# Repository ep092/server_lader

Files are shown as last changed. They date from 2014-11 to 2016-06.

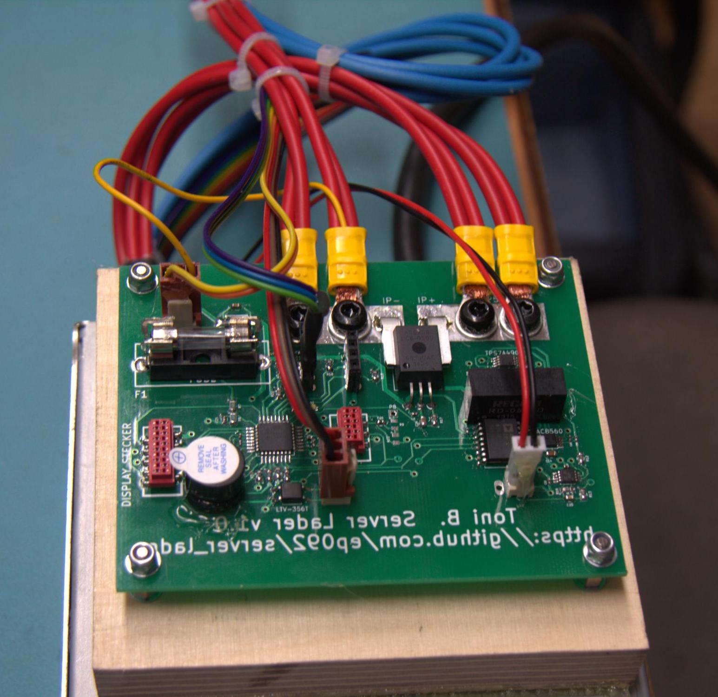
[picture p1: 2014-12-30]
Bilder/Aufbau_phil_2_vorn.JPG

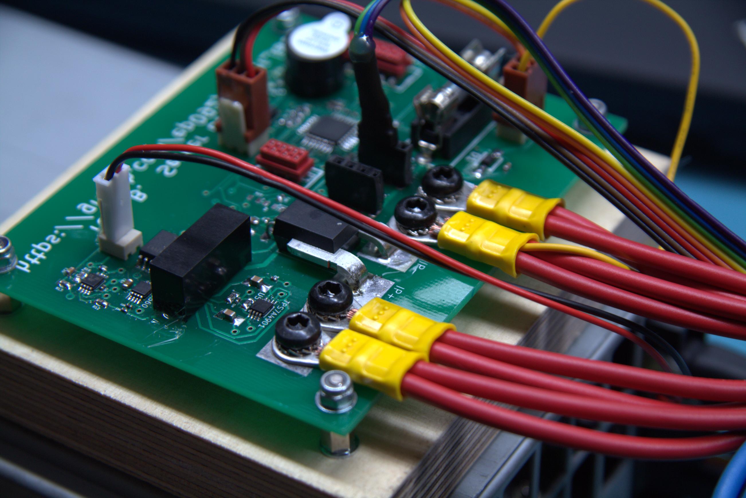
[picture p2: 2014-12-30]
Bilder/Aufbau_phil_3_detail.JPG

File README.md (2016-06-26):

# server_lader

## Umbau eines ESP120 zu einem Ladegerät

### Trivia:
Das ESP120 ist ein 3kW starkes Servernetzteil mit einer Ausgangsspannung von standardmäßig 52V und bis zu >50A. Das Netzteil lässt sich allerdings leicht auf andere Spannungen umrüsten, um z.B. als Akkulader oder sehr potentes Labornetzteil eingesetzt zu werden.

### Was tut dieses Projekt?
dieses Projekt soll die zur Spannungsverstellung nötige Hilfsspannung aus den vom Netzteil zusätzlich bereitgestellten 5V erzeugen, die Ausgangsspannung regeln und für einen Ladestrom nach einem Ladeprogramm, das extern eingespeist wird, einstellen. Das Netzteil muss nur minimal gemoddet werden.

### Der Mod:
siehe elweb, eigene Bilder liegen im Unterordner "Bilder".
Einfach gesagt, werden an den beiden Pads des Potis "RV..." Kabel angelötet, die dann mit der Steuerplatine verbunden werden. Hier wird die Sollwertspannung eingespeist.

Es existieren Messwerte für 3 Sollwertspannungen:

* 61V 35,4 kOhm (-1,5V am Poti)
* 60V 42,5 kOhm (-1,3V am Poti)
* 59V 51,6 kOhm (-1,1V am Poti)

## Umbau auf eine andere Spannung für die Überspannungsabschaltung
Das Netzteil besitzt zusätzlich zur Regelspannung, die am Poti zu verändern ist, eine feste Spannung, bei der eine Überspannungsabschaltung stattfindet. Die soll das Netzteil und die angeschlossenen Verbraucher schützen. Teilweise ist es jedoch nötig, nahe an 60V zu kommen, beispielsweise, wenn man einen 48V-Bleiakkupack laden will. Daher ist in diesen Fällen die Überspannungsabschaltung auf einen leicht höheren Spannungswert zu verschieben. 

Dazu ist es notwendig einen zusätzlichen Widerstand parallel zu den bereits vorhandenen auf einer der Platinen einzulöten. Es handelt sich um einen SMD-Widerstand in Bauform 0805 mit dem Wert "473" also 47 kOhm, der direkt neben einem SMD-Bauteil im Gehäuse SOT-223-3 liegt. Im Ordner "Bilder" ist die Stelle zu sehen, wo der Widerstand eingelötet werden muss.

Wenn man über die bereits verbauten Widerstände im eingebauten Zustand misst, kommt man auf 4,096 Ohm. Mit einem parallel geschaltenen 51,6 kOhm Widerstand kommt man so auf einen Widerstand von 3,79kOhm

Es wird hier allerdings ein Widerstand mit 47 kOhm empfohlen, da mit diesem 60V gerade so erreicht werden, aber die Kondensatoren des Netzteils noch nicht beschädigt werden. Diese halten 63V aus. Für noch höhere Ausgangsspannungen müssten die Kondensatoren durch andere Typen mit 80V Festigkeit getauscht werden. Zusätzlich wird das Netzteil ab ca 61-62V instabil.

## Änderungen für Hardwareversion 2:
 
* Footprint für Stecker anpassen
* zusätzlicher Kondensator für AREF
* Micromatch-Stecker auf Display Platine auf Unterseite verlegen
* zweiter Stecker für I2C, um das OLED anzuschließen (JST XH, stehend)

## TODOs Software:

* I2C-Auswertung von Lüfter und Temperaturen
* Umbau auf so ein kleines OLED-Display z.b. mit der U8g-Lib

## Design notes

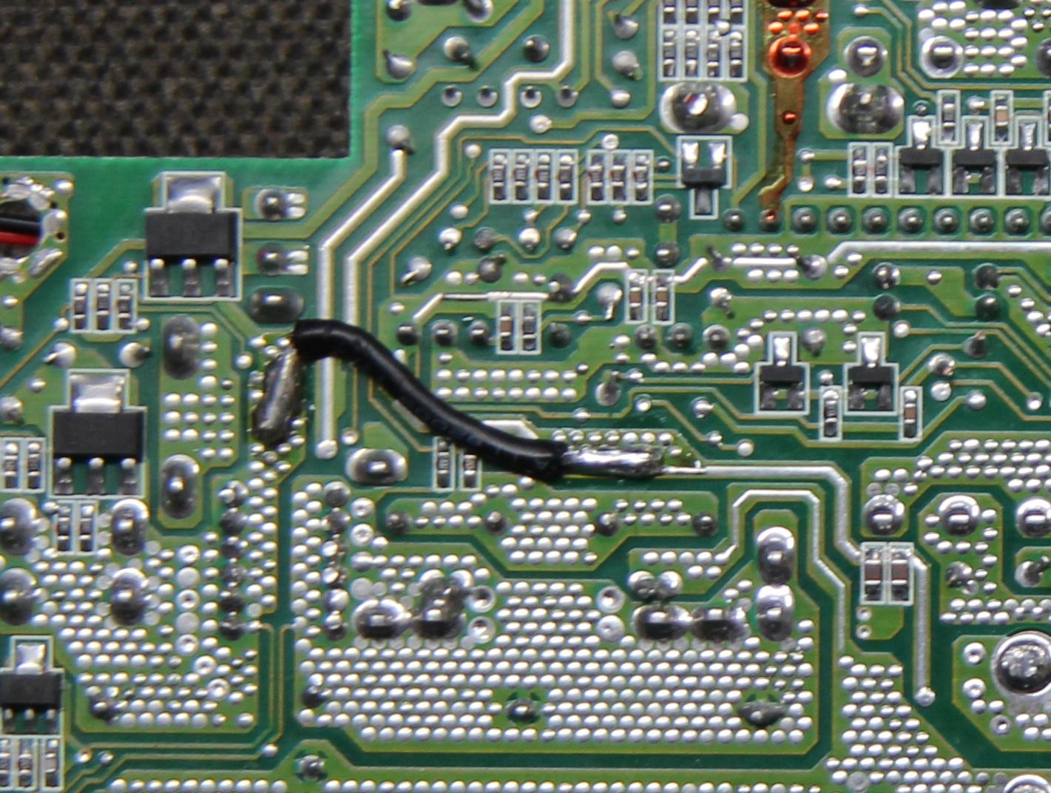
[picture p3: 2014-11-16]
Bilder/Masse gebrückt Detail.jpg

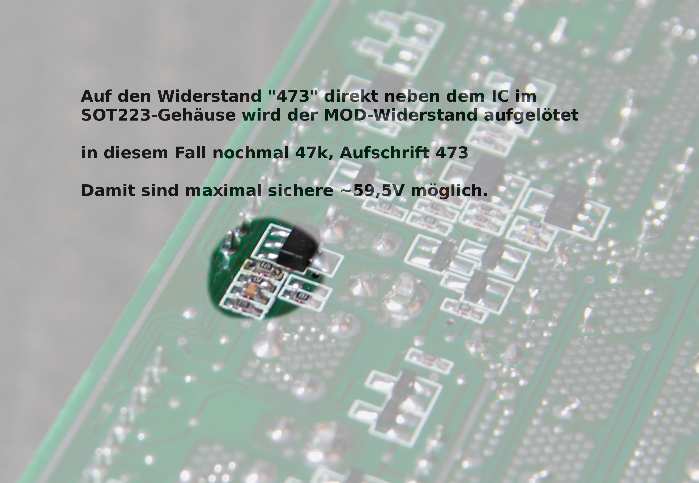
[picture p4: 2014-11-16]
Bilder/Eingelöteter Modwiderstand 47k.png

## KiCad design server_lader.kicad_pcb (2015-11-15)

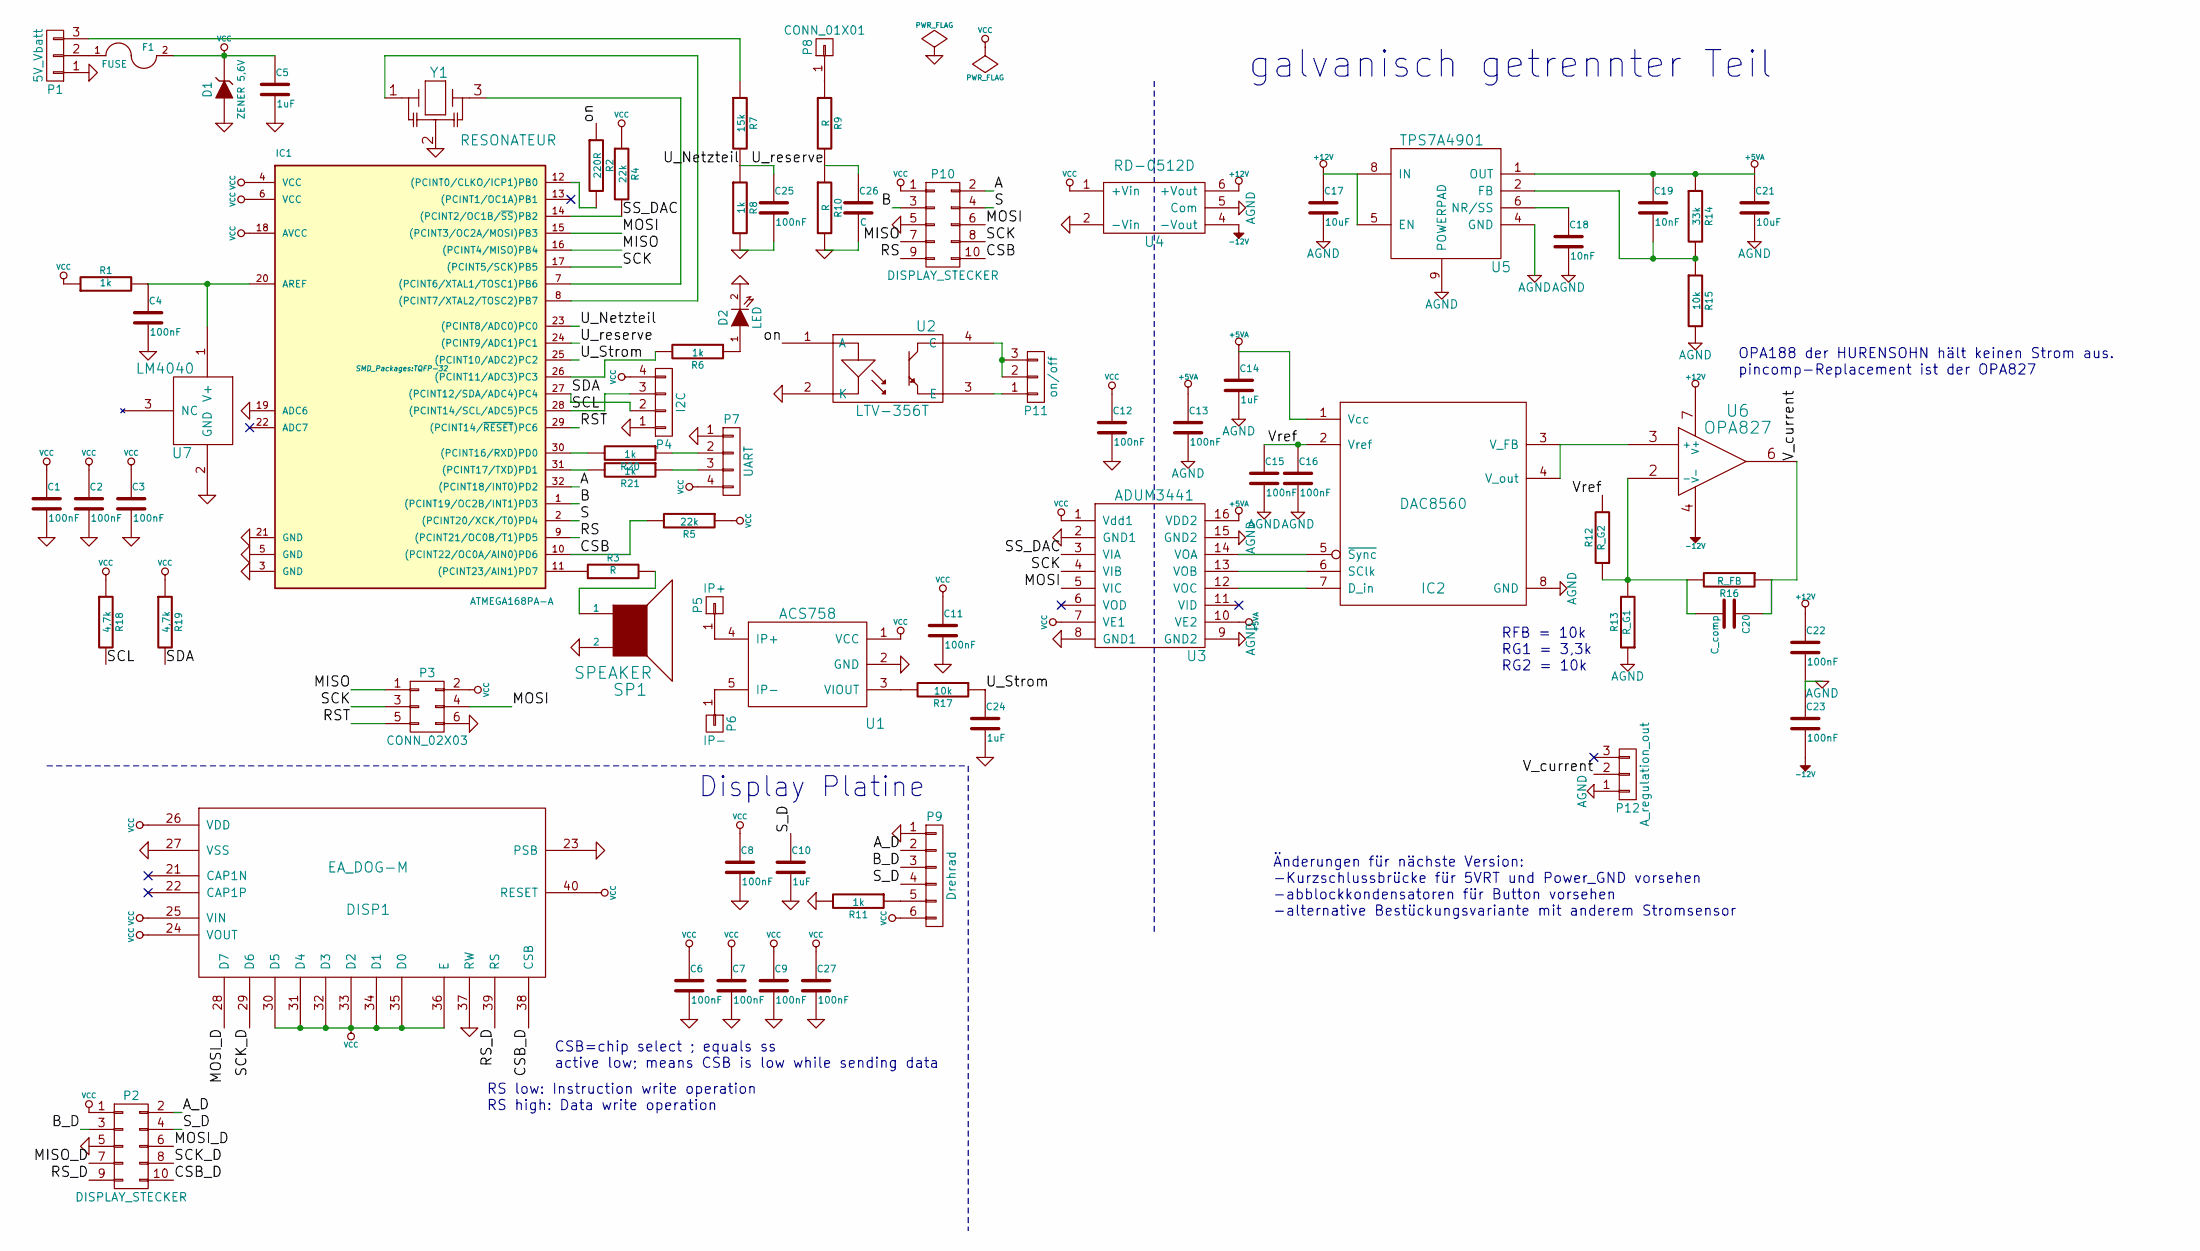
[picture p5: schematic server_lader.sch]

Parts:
C1, C2, C3, C4, C6, C7, C8, C9, C11, C12, C13, C15, C16, C22, C23, C27: 100nF; SMD-0402
C5, C10, C14, C24: 1uF; SMD-0603
C17, C21: 10uF; SMD-1206
C18, C19: 10nF; SMD-0402
C20: C_comp; SMD-0603
C25: 100nF; SMD-0603
C26: C; SMD-0603
D1: ZENER 5,6V; Diode-Universal-SMA-SMB_Handsoldering
D2: LED; SMD-0603
DISP1: EA_DOG-M; EA_DOG-M_DISP
F1: FUSE; fuse_holder_Schurther
IC1: ATMEGA168PA-A; TQFP-32
IC2: DAC8560; MSOP-8_3x3mm_Pitch0.65mm
P1: 5V_Vbatt; Socket_MOLEX-KK-RM2-54mm_Lock_3pin_straight
P2, P10: DISPLAY_STECKER; micro_match5x2
P3: CONN_02X03; micro_match3x2
P4: I2C; Socket_MOLEX-KK-RM2-54mm_Lock_4pin_straight
P5: IP+; power_terminal
P6: IP-; power_terminal
P7: UART; Socket_MOLEX-KK-RM2-54mm_Lock_4pin_straight
P8: CONN_01X01; SIL-1
P9: Drehrad; Socket_MOLEX-KK-RM2-54mm_Lock_6pin_straight
P11: on/off; Socket_MOLEX-KK-RM2-54mm_Lock_3pin_straight
P12: A_regulation_out; Socket_MOLEX-KK-RM2-54mm_Lock_3pin_straight
R1, R6, R8, R11, R20, R21: 1k; SMD-0805
R2: 220R; SMD-0805
R3, R9, R10: R; SMD-0805
R4, R5: 22k; SMD-0805
R7: 15k; SMD-0805
R12: R_G2; SMD-0805
R13: R_G1; SMD-0805
R14: 33k; SMD-0805
R15, R17: 10k; SMD-0805
R16: R_FB; SMD-0805
R18, R19: 4,7k; SMD-0805
SP1: SPEAKER; Buzzer_AI-1027-TWT-5V-R
U1: ACS758; ACS758_PFF
U2: LTV-356T; SO-4
U3: ADUM3441; SOIC-16_7.5x10.3mm_Pitch1.27mm
U4: RD-0512D; RD-xx12D
U5: TPS7A4901; MSOP-8_power_pad
U6: OPA827; SSOP-8
U7: LM4040; SOT-23
Y1: RESONATEUR; CerOsc_3,2x1,3

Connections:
+5VA: C13.1, C14.1, C19.1, C21.1, IC2.1 (Vcc), R14.1, U3.10 (VE2), U3.16 (VDD2), U5.1 (OUT)
+12V: C17.1, C22.1, U4.6 (+Vout), U5.5 (EN), U5.8 (IN), U6.7 (V+)
-12V: C23.2, U4.4 (-Vout), U6.4 (V-)
/A: IC1.32 ((PCINT18/INT0)PD2), P10.2
/A_D: P2.2, P9.2
/B: IC1.1 ((PCINT19/OC2B/INT1)PD3), P10.3
/B_D: P2.3, P9.3
/CSB: IC1.10 ((PCINT22/OC0A/AIN0)PD6), P10.10, R5.2
/CSB_D: DISP1.38 (CSB), P2.10
/MISO: IC1.16 ((PCINT4/MISO)PB4), P3.1, P10.7
/MOSI: IC1.15 ((PCINT3/OC2A/MOSI)PB3), P3.4, P10.6, U3.5 (VIC)
/MOSI_D: DISP1.28 (D7), P2.6
/RS: IC1.9 ((PCINT21/OC0B/T1)PD5), P10.9
/RST: IC1.29 ((PCINT14/~RESET~)PC6), P3.5
/RS_D: DISP1.39 (RS), P2.9
/S: IC1.2 ((PCINT20/XCK/T0)PD4), P10.4
/SCK: IC1.17 ((PCINT5/SCK)PB5), P3.3, P10.8, U3.4 (VIB)
/SCK_D: DISP1.29 (D6), P2.8
/SCL: IC1.28 ((PCINT14/SCL/ADC5)PC5), P4.3, R18.2
/SDA: IC1.27 ((PCINT12/SDA/ADC4)PC4), P4.2, R19.2
/SS_DAC: IC1.14 ((PCINT2/OC1B/~SS~)PB2), R4.2, U3.3 (VIA)
/S_D: C10.1, P2.4, P9.4
/U_Netzteil: C25.1, IC1.23 ((PCINT8/ADC0)PC0), R7.2, R8.1
/U_Strom: C24.1, IC1.25 ((PCINT10/ADC2)PC2), R17.1
/U_reserve: C26.1, IC1.24 ((PCINT9/ADC1)PC1), R9.2, R10.1
/V_current: C20.1, P12.2, R16.1, U6.6
/Vref: C15.1, C16.1, IC2.2 (Vref), R12.2
/on: R2.1, U2.1 (A)
AGND: C13.2, C14.2, C15.2, C16.2, C17.2, C18.2, C21.2, C22.2, C23.1, IC2.8 (GND), P12.1, R13.1, R15.2, U3.9 (GND2), U3.15 (GND2), U4.5 (Com), U5.4 (GND), U5.9 (POWERPAD)
GND: C1.2, C2.2, C3.2, C4.2, C5.2, C6.2, C7.2, C8.2, C9.2, C10.2, C11.2, C12.2, C24.2, C25.2, C26.2, C27.2, D1.1 (A), D2.2 (K), DISP1.23 (PSB), DISP1.27 (VSS), DISP1.37 (RW), IC1.3 (GND), IC1.5 (GND), IC1.19 (ADC6), IC1.21 (GND), P1.1, P2.5, P3.6, P4.1, P7.1, P9.1, P10.5, R8.2, R10.2, R11.2, SP1.2, U1.2 (GND), U2.2 (K), U3.2 (GND1), U3.8 (GND1), U4.2 (-Vin), U7.2 (GND), Y1.2
unnamed: C4.1, IC1.20 (AREF), R1.2, U7.1 (V+)
unnamed: C18.1, U5.6 (NR/SS)
unnamed: C19.2, R14.2, R15.1, U5.2 (FB)
unnamed: C20.2, R12.1, R13.2, R16.2, U6.2 (-)
unnamed: D2.1 (A), R6.1
unnamed: F1.1, P1.2
unnamed: IC1.7 ((PCINT6/XTAL1/TOSC1)PB6), Y1.3
unnamed: IC1.8 ((PCINT7/XTAL2/TOSC2)PB7), Y1.1
unnamed: IC1.11 ((PCINT23/AIN1)PD7), R3.1
unnamed: IC1.12 ((PCINT0/CLKO/ICP1)PB0), R2.2
unnamed: IC1.26 ((PCINT11/ADC3)PC3), R6.2
unnamed: IC1.30 ((PCINT16/RXD)PD0), R20.2
unnamed: IC1.31 ((PCINT17/TXD)PD1), R21.2
unnamed: IC2.3 (V_FB), IC2.4 (V_out), U6.3 (+)
unnamed: IC2.5 (~Sync), U3.14 (VOA)
unnamed: IC2.6 (SClk), U3.13 (VOB)
unnamed: IC2.7 (D_in), U3.12 (VOC)
unnamed: P1.3, R7.1
unnamed: P5.1, U1.4 (IP+)
unnamed: P6.1, U1.5 (IP-)
unnamed: P7.2, R20.1
unnamed: P7.3, R21.1
unnamed: P8.1, R9.1
unnamed: P9.5, R11.1
unnamed: P11.1, U2.3 (E)
unnamed: P11.2, P11.3, U2.4 (C)
unnamed: R3.2, SP1.1
unnamed: R17.2, U1.3 (VIOUT)
VCC: C1.1, C2.1, C3.1, C5.1, C6.1, C7.1, C8.1, C9.1, C11.1, C12.1, C27.1, D1.2 (K), DISP1.24 (VOUT), DISP1.25 (VIN), DISP1.26 (VDD), DISP1.30 (D5), DISP1.31 (D4), DISP1.32 (D3), DISP1.33 (D2), DISP1.34 (D1), DISP1.35 (D0), DISP1.36 (E), DISP1.40 (RESET), F1.2, IC1.4 (VCC), IC1.6 (VCC), IC1.18 (AVCC), P2.1, P3.2, P4.4, P7.4, P9.6, P10.1, R1.1, R4.1, R5.1, R18.1, R19.1, U1.1 (VCC), U3.1 (Vdd1), U3.7 (VE1), U4.1 (+Vin)

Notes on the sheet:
galvanisch getrennter Teil
CSB=chip select ; equals ss active low; means CSB is low while sending data
RS low: Instruction write operation RS high: Data write operation
Display Platine
RFB = 10k RG1 = 3,3k RG2 = 10k
Änderungen für nächste Version: -Kurzschlussbrücke für 5VRT und Power_GND vorsehen -abblockkondensatoren für Button vorsehen -alternative Bestückungsvariante mit anderem Stromsensor
OPA188 der HURENSOHN hält keinen Strom aus. pincomp-Replacement ist der OPA827

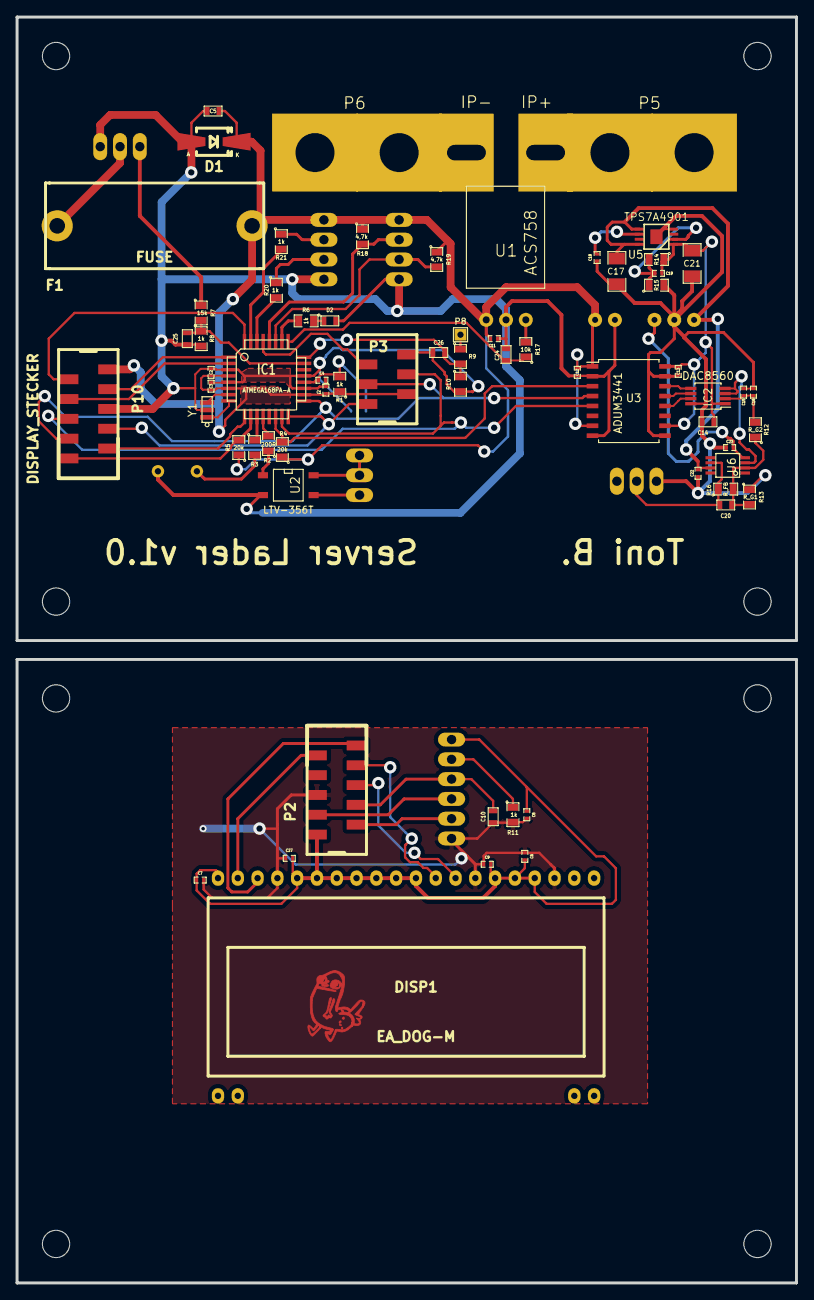
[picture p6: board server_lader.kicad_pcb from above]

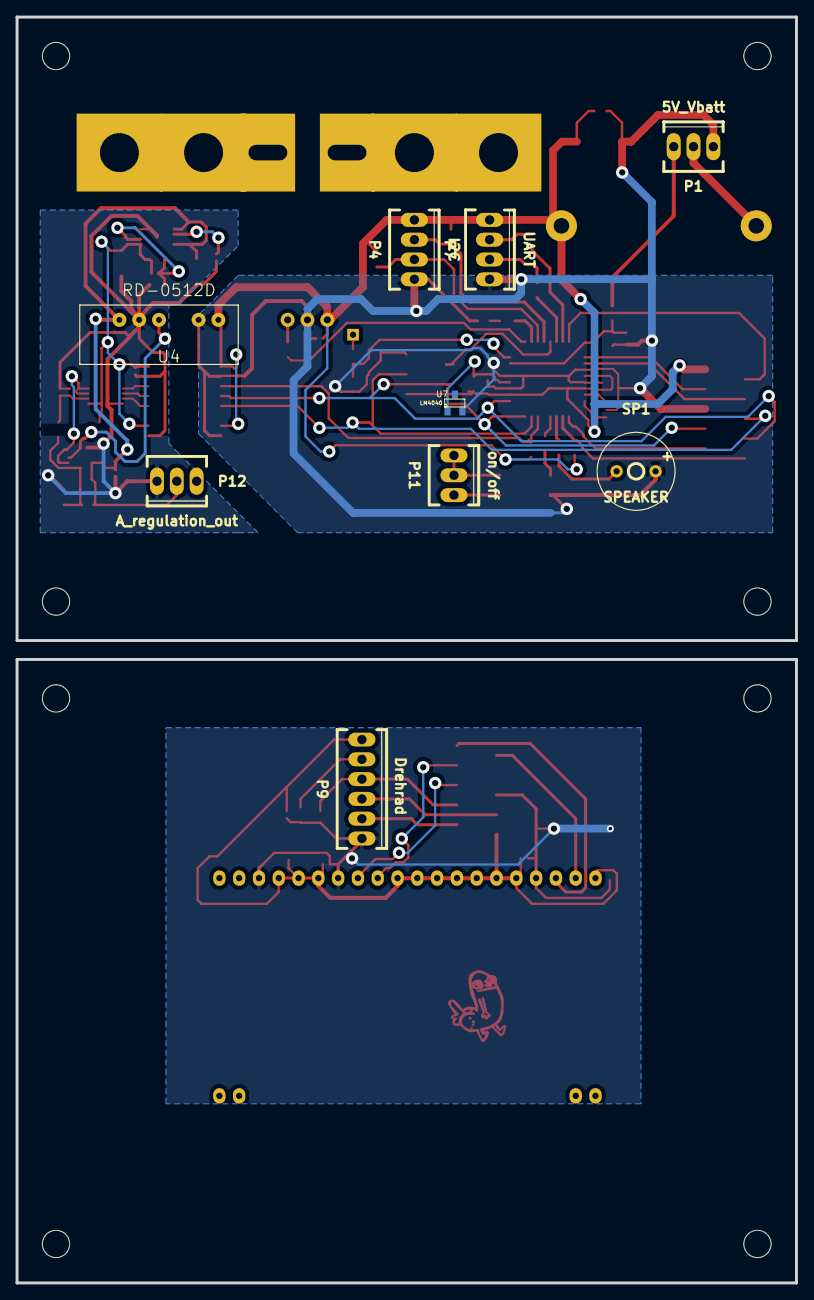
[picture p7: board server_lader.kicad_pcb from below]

Board: 2 copper layers, 100.0 x 162.4 mm, 77 parts (9 on the bottom side), 59 nets.

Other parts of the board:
Outl: EuroBoard_halb_Type-I_100mmX80mm_holes
Outl#2: EuroBoard_halb_Type-I_100mmX80mm_holes

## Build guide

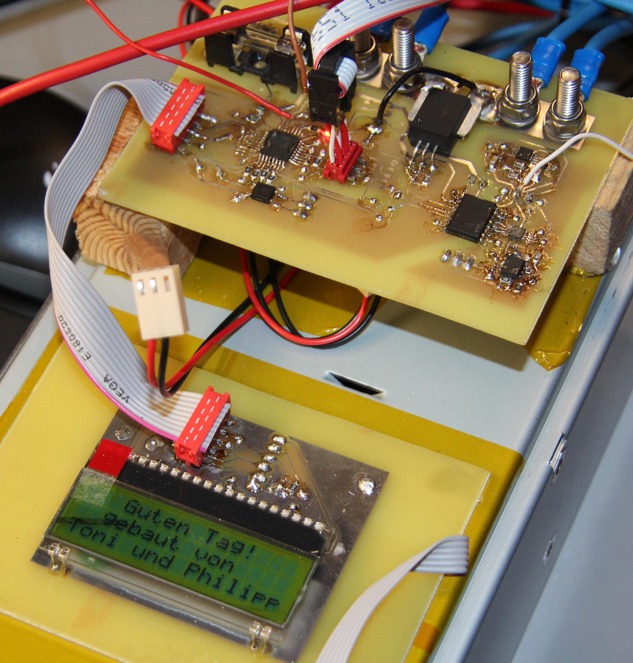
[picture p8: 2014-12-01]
Bilder/Testaufbau_2_Begrüßung.jpg

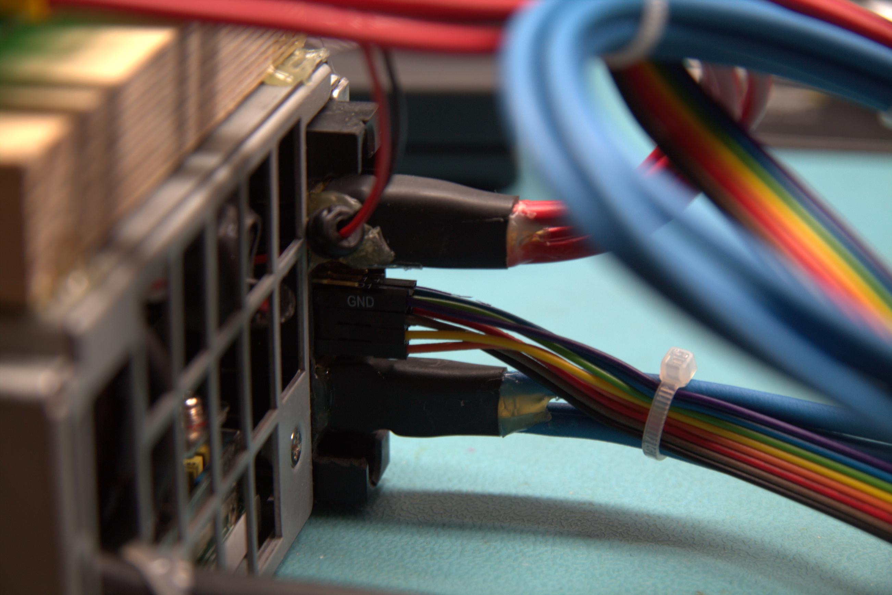
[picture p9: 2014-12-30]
Bilder/Aufbau_phil_4_verkabelung_NT.JPG

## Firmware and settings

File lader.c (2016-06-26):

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
 

#include <avr/interrupt.h>
#include <avr/io.h>
#include <stdio.h>
#include <avr/pgmspace.h>
#include <string.h>
#include <avr/wdt.h>

#include "../AtmelLib/global.h"
#include "../AtmelLib/io/io.h"

// UART RX Interrupt wird aktiviert - Gerät kann damit auf Fernsteuerbefehle reagieren
#define FERNSTEUERUNG

#define I2C_DDR DDRC
#define I2C_PORT PORTC
#define I2C_PIN PINC
#define SCL PC5
#define SDA PC4
uint8_t ERR = 0;
#include "../AtmelLib/io/serial/i2c.h"

// UART: 19200 Baud, 1 Stopbit, no Parity, 8 Bit/frame
#define UBRRH_VALUE 0
#define UBRRL_VALUE 51
#include "../AtmelLib/io/serial/uart.h"

// #define OLED

#ifndef OLED
#define DISPLAY_RS_DDR   DDRD
#define DISPLAY_RS_PORT	 PORTD
#define DISPLAY_RS_PIN	 PD5
#define DISPLAY_CSB_DDR  DDRD
#define DISPLAY_CSB_PORT PORTD
#define DISPLAY_CSB_PIN  PD6
#include "EA_DOGM163L-A-Atmel-Lib/EA_DOGM163L-A.c"
#endif

#ifdef OLED
// OLED-Lib einbinden
#endif

#define LED(x) out(PORTC,PC3,0,x)
// #define NT_ON(x) out(PORTB,PB0,0,x)
#define SPKR(x) out(PORTD,PD7,0,x)
#define SS_DAC(x) out(PORTB,PB2,0,x)

#define B_KNOPF_LOSGELASSEN (knopf & 1) 
#define RESET_KNOPF_LOSGELASSEN cbi(knopf, 0) 
#define B_KNOPF_GEDRUECKT ((knopf >> 1) & 1) 
#define RESET_KNOPF_GEDRUECKT cbi(knopf, 1) 
#define B_STEP_LINKS ((knopf >>3) & 1) 
#define RESET_STEP_LINKS cbi(knopf, 3) 
#define B_STEP_RECHTS ((knopf >>2) & 1) 
#define RESET_STEP_RECHTS cbi(knopf, 2) 

// Umlaute für das Display
#define AE 0b10001110
#define ae 0b10000100
#define OE 0b10011001
#define oe 0b10010100
#define UE 0b10011010
#define ue 0b10000001


volatile uint16_t MAXIMALSPANNUNG = 61000; // in mV, ab hier wird der Errorstate betreten!
volatile uint16_t STROMOFFSET = 593; // wird durch das Netzgeraet automatisch kalibriert

typedef enum {
	INIT_STATE, AUSWAHL, MODUS_LADER, MODUS_NETZGERAET, REGELUNG_NETZGERAET,
	LADEN_AKTIV, LADUNG_FERTIG, ERROR_STATE
} state_main;

typedef enum {
	LADESCHLUSSSPANNUNG, MAXIMALSTROM, STROM_ENDE, START, ZURUECK
} state_modus_lader;

typedef enum { // Die verschiedenen Errorgründe.
	OVERVOLTAGE_ERR, OVERCURRENT_ERR, OVERPOWER_ERR, OVERTEMP1_ERR,
	OVERTEMP2_ERR, TIEFENTLADEN, AKKU_FALSCH_HOCH, AKKU_FALSCH_TIEF,
	NONE, REGLER_RAMP_UP
} state_errors;

state_main state = INIT_STATE;
state_modus_lader state_lader = LADESCHLUSSSPANNUNG;
state_errors errors = NONE;

uint16_t netzgeraet_spannung = 32000;
uint16_t netzgeraet_strom = 12000;

// Anpassungen für das EL mit 2*34 NiCd Zellen
uint16_t modus_lader_ladeschlussspannung = 55000;
uint16_t modus_lader_maximalstrom = 48000;
uint16_t modus_lader_strom_ende = 4000;

char display[17];


volatile uint8_t knopf=0;
// knopf-Datentyp:	7:0 		6:0 		5:STEP_TEMP_LINKS 	4:STEP_TEMP_RECHTS
//			3:STEP_LINKS 	2:STEP_RECHTS 	1:KNOPF-GEDRÜCKT 	0:KNOPF-LOSGELASSEN
// Drehung Pin 1


void adcInit(void) {
	ADMUX = 0; // Referenz auf externe Referenz
	ADCSRA = 1<<ADEN | 1<<ADSC | 1<<ADIE | 5<<ADPS0; // ADC an, Interrupt an, Prescaler=128
	ADCSRB = 0; // nicht verwendet.
}

void adcStart(void) {
	ADCSRA |= 1<<ADSC;
}

void dacSetValue(uint16_t wert, uint8_t mode) {
	uint8_t tempspcr = SPCR; // sichere den Stand von SPCR
	SPCR = 1<<SPE | 1<<MSTR | 1<<CPOL; // SPI MSB first, Clock on falling edge, sample on leading, VOLLGAS
	SS_DAC(0); // SS_DAC ist low active
	SPDR = (0b00000011 & mode); // sende PowerDown-Mode
	while (!(SPSR & (1<<SPIF))); // warte auf Transmission complete
	SPDR = (wert>>8); // sende oberen Teil vom Datenwort
	while (!(SPSR & (1<<SPIF)));
	SPDR = (wert & 0xff); // sende unteren Teil vom Datenwort
	while (!(SPSR & (1<<SPIF)));
	SS_DAC(1);
	SPCR = tempspcr;
}

void ntOn(uint8_t ausgang) {
	// (PORTB,PB0,0,x)
	if (ausgang == 0) {
		cbi(PORTB, PB0);
		wdt_disable();
	} else {
		wdt_enable(WDTO_500MS);
		sbi(PORTB, PB0);
	}
}

#define RFB 10000
#define RG1 3300
#define RG2 10000
#define DAC_REF 2.5
#define T 55.44
#define M -4.9

// K1 = 1+(RFB/RG2)+(RFB/RG1)	// K1 = 5,0303
// K2 = (RFB/RG2)*DAC_REF 	// K2 = 2,5

#define K1 5.0303
#define K2 2.5

inline void setPowerOutput(uint16_t millivolt) {
	// Berechnung des DAC-wertes aus der sollspannung
	dacSetValue((uint16_t)(((((((float)millivolt / 1000) - T) / M) + K2) * 65536) / (K1 * DAC_REF)), 0);
}

void timerInit(void) {
	// Timer/Counter1 im CTC modus verwenden. alle 10ms ein Interrupt
	TCCR1A = 0; // CTC (mode 4)
	TCCR1B = 1<<WGM12 | 1<<CS11 | 1<<CS10; // CTC (mode 4), Prescaler = 64 -> 4µs pro Timerschritt
	TIMSK1 = 1<<OCIE1A; // Interrupt on compare match
	OCR1A  = 1250; // TOP und Interrupt alle 10ms bei 16MHz clockspeed
}

// Der ADC wird interruptgesteuert
volatile uint8_t counter = 0, zaehler = 0;
// nötig für Berechnung der Netzteilleistung und der gelandenen Energiemenge
volatile float leistung = 0, energie = 0, fuellstand = 0;
volatile uint16_t uNetzteil=0, uReserve=0, strom=0; // U in mV, I in mA

ISR (TIMER1_COMPA_vect, ISR_BLOCK) {
	ADMUX = ADMUX & 0b11100000; // lösche selektiv die MUX-Bits
	ADMUX |= (counter%3); // setze ADC-Kanal neu
	ADCSRA |= 1<<ADSC; // start conversion
	zaehler++;
	if (zaehler == 100) { // es ist eine Sekunde vergangen!
		energie += ((float)strom * (float)uNetzteil) /1000; // in Wattsekunden
		fuellstand += (float)strom /3600; // in mAh
		zaehler = 0;
	}
}


// Drehrad Interrupts
ISR (INT0_vect, ISR_BLOCK) {
	if(knopf & 1<<5) { // Knopf wurde eins nach links gedreht
		sbi(knopf, 3);
		cbi(knopf, 5);
	} else { // knopf wurde eins nach rechts gedreht
		sbi(knopf, 4);
	}
}

// Drehung Pin 2
ISR (INT1_vect, ISR_BLOCK) {
	if(knopf & 1<<4) { // Knopf wurde eins nach rechts gedreht
		sbi(knopf, 2);
		cbi(knopf, 4);
	} else { // knopf wurde eins nach links gedreht
		sbi(knopf, 5);
	}	
}

// KNOPFDRUCK oder loslassen
ISR (PCINT2_vect, ISR_BLOCK) {
	if(PIND & 1<<PD4) { // Knopf ist gerade losgelassen worden
		sbi(knopf, 0);
		cbi(knopf, 1); // lösche gedrückt-Bit wieder
	} else { // Knopf gedrückt, warte auf loslassen
		sbi(knopf, 1); // setze gedrückt-Bit
		cbi(knopf, 0); //lösche losgelassen bit wenn taster gedrückt ist
	}
}

// UART Receive Complete Interrupt
volatile char tempstring[21], tempchar = 0;
volatile uint8_t uartAktuell = 0, uartLastChar = 0;
ISR (USART_RX_vect, ISR_BLOCK) {
	static uint8_t position = 0;
	static char empfangsdaten[21];
	tempchar = UDR;
	uartLastChar = 1; // Ein Zeichen empfangen
	
	// nur schreibbare Zeichen in den Puffer übernehmen, wenn das letzte Frame
	// schon verarbeitet wurde.
	if (uartAktuell == 0) {
		if (tempchar >= 0x21) {
			empfangsdaten[position] = tempchar;
			position++;
			
			// remote echo nur für Zeichen, die in den Puffer übernommen werden
			uartTx(tempchar);
		}		
		if ((position == 20) || tempchar == 0x0D || tempchar == '\n') {
			strcpy (tempstring, empfangsdaten);
			for(uint8_t i=0; i<21; i++) {
				empfangsdaten[i] = 0; // lösche empfangsdaten
			}
			position = 0;
			uartAktuell = 1;
			uartLastChar = 0;
		}
	}
}


// ADC Conversion complete Interrupt
// ADC0 = uNetzteil, ADC1 = uReserve, ADC2 = strom
// Die Werte können noch kalibriert werden, allerdings nicht zur Laufzeit.

#define REFERENZ 4	// externe Referenz, 4096mV also 4mV pro STEP
#define ABWEICHUNG 1.000296589  // gemessene Abweichung in % vom exakten Referenzspannungswert
#define MITTELWERTE 4

ISR (ADC_vect, ISR_BLOCK) {
	// uartTxStrln("adc");
	// ADC-Auslesungen und Rechnung mit Gleitmittelwert über 4 Werte
	static uint16_t tabelle[3*MITTELWERTE]; // hier kommen die ADC-werte rein.
	uint16_t temp=0;
	tabelle[counter] = ADC; // fülle Tabelle mit ADC-Werten
	
	switch (counter%3) {
		case 0:
			// uNetzteil wird ausgerechnet
			for(uint8_t i=0; i<MITTELWERTE; i++) {
				temp += tabelle[0 + 3*i];
			}
			uNetzteil = (uint16_t)((temp*REFERENZ)<<2)*ABWEICHUNG;
			break;
			
		case 1:
			// uReserve wird ausgerechnet
			for(uint8_t i=0; i<MITTELWERTE; i++) {
				temp += tabelle[1 + 3*i];
			}
			uReserve = (uint16_t)((temp*REFERENZ)<<2)*ABWEICHUNG;
			break;
			
		case 2:
			// strom wird ausgerechnet
			for(uint8_t i=0; i<MITTELWERTE; i++) {
				temp += tabelle[2 + 3*i];
			}

			strom = (uint16_t)((float)temp*ABWEICHUNG*((float)50/(float)3));
			if (strom < STROMOFFSET) {
				strom = 0;
			} else {
				strom -= STROMOFFSET;
			}
			break;
	}
	counter++;
	if (counter == 3*MITTELWERTE) { // setze Counter zurück
		counter = 0;
	}
	leistung = ((float)uNetzteil * (float)strom) / 1000; // Leistung in Watt
}

uint8_t knopf_losgelassen(void) {
	uint8_t return_value = B_KNOPF_LOSGELASSEN;
	delayms(10);
	if (return_value != B_KNOPF_LOSGELASSEN){	//entprellen
		return_value = B_KNOPF_LOSGELASSEN;
	}
		
	if(return_value){
		SPKR(1);
		delayms(10);
		SPKR(0);
		RESET_KNOPF_LOSGELASSEN;
		RESET_KNOPF_GEDRUECKT;
	}
	return return_value;
}

uint8_t knopf_gedrueckt(void) {
	uint8_t return_value = B_KNOPF_GEDRUECKT;
	RESET_KNOPF_GEDRUECKT;
	return return_value;
}

uint8_t step_links(void) {
	uint8_t return_value = B_STEP_LINKS;
	RESET_STEP_LINKS;
	if(return_value){
		SPKR(1);
		delayms(10);
		SPKR(0);
	}
	return return_value;
}

uint8_t step_rechts(void) {
	uint8_t return_value = B_STEP_RECHTS;
	RESET_STEP_RECHTS;
	if(return_value){
		SPKR(1);
		delayms(10);
		SPKR(0);
	}
	return return_value;
}

uint16_t spannungseinstellung(uint16_t lokalspannung) {
	while(knopf_losgelassen()!=1){
		sprintf(display, "Uout: %5umV ", lokalspannung);
		display_set_row(2);
		spi_write_string(display);
		if (step_links()){
			lokalspannung -=100;
		}else if (step_rechts()){
			lokalspannung += 100;
		}
	}
	return lokalspannung;
}

uint16_t stromeinstellung(uint16_t lokalstrom) {
	while(knopf_losgelassen()!=1){
		sprintf(display, "Iout: %5umA ", lokalstrom);
		display_set_row(2);
		spi_write_string(display);
		if (step_links()){
			lokalstrom -=100;
		} else if (step_rechts()){
			lokalstrom += 100;
		}
	}
	return lokalstrom;
}

void netzteil_regulation(void) {
	uartTxStrln("Netzteil aktiv");
	uartAktuell = 1;
// 	nötig zur Kalibrierung!
	STROMOFFSET = 0;
	delayms(200);
	cli();
	uint16_t ulokal = uNetzteil, ilokal = strom;
	sei();
	errors = NONE; // lösche Fehlerspeicher
	STROMOFFSET = ilokal; // Offset wird beim Start des Netzteils rauskalibriert.
	int regelspannung = 0;
	uint8_t run = 1;
	// Voreinstellung des DACs, damit dieser keinen zu großen Sprung ausführen muss
	// TODO: prüfen ob das nötig ist.
	if (netzgeraet_spannung > 6000) {
		setPowerOutput(netzgeraet_spannung - 6000);
	} else {
		setPowerOutput(netzgeraet_spannung);
	}
	display_set_row(0);
	spi_write_pstr(PSTR("Netzger"));
	spi_write_char(ae);
	spi_write_pstr(PSTR("t AKTIV "));
	delayms(500);
	uartTxPstrln(PSTR("Netzgerät schaltet Ausgänge an"));
	uartTxPstrln(PSTR("Bedienung: Spannung verringern mit -, erhöhen mit +"));
	uartTxPstrln(PSTR("Verlassen des Netzteilmodus mit Knopfdruck auf x"));
	ntOn(1); // Output ON
	
	// Betrete Regelschleife, in der die Spannung konstant gehalten wird.
	// wenn Knopf gedrückt oder Error passiert, wieder NT-Modus verlassen
	while ((knopf_losgelassen() == 0) && (state != ERROR_STATE) && run) {
		
		cli();
		ulokal = uNetzteil;
		ilokal = strom;
		sei();
		
		display_set_row(1);
		sprintf(display, "U_out: %5u mV ", ulokal); // Netzteilspannung anzeigen
		spi_write_string(display);
		display_set_row(2);
		sprintf(display, "I_out: %5u mA ", ilokal); // Laststrom anzeigen
		spi_write_string(display);
		
		if (ilokal > netzgeraet_strom) {
			ntOn(0); // Netzteil AUS. Überstrom!
			state = ERROR_STATE;
			errors = OVERCURRENT_ERR;
			uartTxPstrln(PSTR("ERROR - Strom weit über eingestelltes Limit gestiegen!"));
			SPKR(1);
			delayms(1000); // TÜÜT
			SPKR(0);
			continue;
			
		}
		if (ulokal > (netzgeraet_spannung + 1500)) {
			ntOn(0); // Netzteil AUS. Überspannung!
			state = ERROR_STATE;
			errors = OVERVOLTAGE_ERR;
			uartTxPstrln(PSTR("ERROR - Überspannung!"));
			SPKR(1);
			delayms(1000); // TÜÜT
			SPKR(0);
			continue;
			
		}
		if (ulokal - 100 > netzgeraet_spannung) { // Ausgangsspannung zu hoch
			if (regelspannung > 0) {
				regelspannung--;
			}
			delayms(1); // Zeitkonstante künstlich erhöht, damit Regelung nicht schwingt.
			
		}
		if (ulokal + 100 < netzgeraet_spannung) { // Ausgangsspannung zu klein
			if (regelspannung < 256) {
				regelspannung++;
			} else {
				// Regler Ramp-up Error!
				ntOn(0);
				state = ERROR_STATE;
				errors = REGLER_RAMP_UP;
				uartTxPstrln(PSTR("Regler zu weit aufgedreht - evtl. Spannungsmessung defekt"));
				SPKR(1);
				delayms(1000); // TÜÜT
				SPKR(0);
				continue;
			}
			delayms(1);
		}
		
		// Normaler Betrieb, Spannung kann verstellt werden
		if (step_links() && (netzgeraet_spannung > 100)) { // Spannung um 100mV runter, minimal 0V
			netzgeraet_spannung = netzgeraet_spannung - 100;
		}
		
		if (step_rechts() && ((netzgeraet_spannung + 100) < MAXIMALSPANNUNG)) { // Spannung um 100mV hoch
			netzgeraet_spannung = netzgeraet_spannung + 100;
		}
		
		if (uartLastChar) {
			uartLastChar = 0;
			cli();
			uint8_t zeichen = tempchar;
			sei();
			switch (zeichen) {
				case 'x':
					run = 0;
				break;
				
				case '+':
					if ((netzgeraet_spannung + 100) < MAXIMALSPANNUNG) {
						netzgeraet_spannung = netzgeraet_spannung + 100;
					}
				break;
				
				case '-':
					if (netzgeraet_spannung > 100) {
						netzgeraet_spannung = netzgeraet_spannung - 100;
					}
				break;
				default :
					;
				break;
			}
		}
		
		// Text überschreibt sich auch hier selber
		uartTxStr("U=");
		uartTxDec(ulokal);
		uartTxStr(" mV, I=");
		uartTxDec(ilokal);
		uartTxStr(" mA, Imax=");
		uartTxDec(netzgeraet_strom);
		uartTxStr(" mA     ");
		uartTx(0x0D);
		
		if (((netzgeraet_spannung - 300) + regelspannung * 8) > MAXIMALSPANNUNG) {
			; // do nothing.
		} else {
			setPowerOutput((netzgeraet_spannung - 300) + regelspannung * 12);
		}
		wdt_reset();
	}
	// ENDE. Netzteil wird abgeschaltet und State verlassen
	if (errors == NONE) {
		state = MODUS_NETZGERAET;
		uartTxPstrln(PSTR("Netzteil wieder ausgeschaltet - kehre zum Menü zurück"));
	}
	ntOn(0);
	delayms(100);
}

void ladung_regulation(void) {
	uartTxPstrln(PSTR("LADEN_AKTIV"));
	uartAktuell = 1;
	// Lokale Schutzgrenzen - 10% über Lademaximalwerten
	STROMOFFSET = 0;
	delayms(200);
	cli();
	uint16_t ulokal = uNetzteil, ilokal = 0; // werden aus uNetzteil und strom erzeugt, damit interrupts
	// nicht die Regelung stören.
	sei();
	uint16_t umax = modus_lader_ladeschlussspannung + (modus_lader_ladeschlussspannung/10);
	uint16_t imax = modus_lader_maximalstrom + (modus_lader_maximalstrom/5);
	uint16_t tempspannung = ulokal - 1000; // Anfangsspannung ist 2V unter aktueller Akkuspannung
	energie = 0;
	errors = NONE;
	delayms(1000);
	STROMOFFSET = strom; // calibrate
	
	if (ulokal > modus_lader_ladeschlussspannung) { // Akku schon voll oder falsche Einstellungen!
		// ABBRUCH!
		state = ERROR_STATE;
		errors = AKKU_FALSCH_HOCH;
		uartTxPstrln(PSTR("ERROR - Akkuspannung über Ladeschlussspannung"));
		// Meldung bringen a "maybe falscher Akku oder sowas"
		
	}
	if (ulokal < (modus_lader_ladeschlussspannung/3)) { // Akku wohl tiefentladen (NiCd kann unter 50% haben!)
		// ABBRUCH!
		state = ERROR_STATE;
		errors = AKKU_FALSCH_TIEF;
		uartTxPstrln(PSTR("ERROR - Akku ist wohl Tiefentladen"));
		// Meldung: akku tiefentladen oder falsche Ladeschlussspannung eingestellt
		
	} else { // normaler Modus; aktiviere Output und Regelschleife
		// Output wird auf 5V weniger als die aktuell gemessene Spannung gesetzt.
		uartTxPstrln(PSTR("Ladeparameter:"));
		uartTxStr("Uend = ");
		uartTxDec(modus_lader_ladeschlussspannung);
		uartTxNewline();
		uartTxStr("Imax = ");
		uartTxDec(modus_lader_maximalstrom);
		uartTxNewline();
		uartTxStr("Iend = ");
		uartTxDec(modus_lader_strom_ende);
		uartTxNewline();
		
		setPowerOutput(tempspannung);
		delayms(200);
		display_clear();
		display_set_row(0);
		spi_write_pstr(PSTR("Akku l"));
		spi_write_char(ae);
		spi_write_pstr(PSTR("dt auf!"));
		uartTxPstrln(PSTR("Starte Netzgerät und lade den Akku"));
		ntOn(1); // Output ON
		
		// Betrete Regelschleife, in der die Spannung konstant gehalten wird.
		// wenn Knopf gedrückt oder Error passiert, wieder NT-Modus verlassen
		while ((knopf_losgelassen() == 0) && (state == LADEN_AKTIV)) {
			
			cli(); // u und i werden ausgelesne und gecacht
			ulokal = uNetzteil;
			ilokal = strom;
			sei();
			
			display_set_row(1); // U und I
			snprintf(display, 17, "U=%5u I=%5u", ulokal, ilokal);
			spi_write_string(display);
			display_set_row(2); // P[W] und E[Ah]
			snprintf(display, 17, "P=%5u E=%5u", (uint16_t)leistung, (uint16_t)fuellstand);
			spi_write_string(display);
			if (ilokal > imax) {
				state = ERROR_STATE;
				errors = OVERCURRENT_ERR;
				uartTxPstrln(PSTR("ERROR - Überstrom beim Laden"));
				ntOn(0); // Netzteil AUS. Überstrom!
				SPKR(1);
				delayms(1000); // TÜÜT
				SPKR(0);
				
			}
			if (ulokal > umax) {
				state = ERROR_STATE;
				errors = OVERVOLTAGE_ERR;
				uartTxPstrln(PSTR("ERROR - Überspannung beim Laden"));
				ntOn(0); // Netzteil AUS. Überspannung!
				SPKR(1);
				delayms(1000); // TÜÜT
				SPKR(0);
			}
			
			// Regelung so, dass der Sollstrom erreicht wird, aber die Ladeschlussspannung nicht überschritten.
			if (ulokal < (modus_lader_ladeschlussspannung+100)) { // CC modus, Akkus werden vollgedrückt
				if (ilokal < (modus_lader_maximalstrom - 10)) {
					tempspannung +=6;
					delayms(1);
				} else if (ilokal > (modus_lader_maximalstrom + 10)) {
					tempspannung -=6;
					delayms(1);
				}
			} 
			if (ulokal > modus_lader_ladeschlussspannung) { // CV modus, Akkus fast voll.
				// Ladespannung (tempspannung) nicht ändern.
				if (ilokal < modus_lader_strom_ende) { // Akku voll. BEENDE LADUNG
					state = LADUNG_FERTIG;
					errors = NONE;
					ntOn(0);
					uartTxPstrln(PSTR("ERFOLG - Akku fertig aufgeladen"));
					uartTxPstrln(PSTR("Bestätigen mit ok"));
					for (uint8_t i=0; i<5; i++) {
						SPKR(1);
						delayms(100);
						SPKR(0);
						delayms(500);
					}
				}
				if (ulokal > (modus_lader_ladeschlussspannung + 100) || (ilokal > modus_lader_maximalstrom + 100)) {
					// wenn durch transiente Effekte tempspannung oder Ladestrom zu hoch wurde...
					tempspannung -=100;
				}
			}
			if (uartLastChar) {
				uartLastChar = 0;
				if (tempchar == 'x') {
					state = AUSWAHL;
					uartTxPstrln(PSTR("Ladung abgebrochen - kehre zurück ins Hauptmenü"));
					errors = NONE;
					ntOn(0);
					continue;
				}
			}
// 			keine neue Zeile nach der Meldung - Text überschreibt sich selbst.
			uartTxStr("U=");
			uartTxDec(ulokal);
			uartTxStr(" mV, I=");
			uartTxDec(ilokal);
			uartTxStr(" mA, C=");
			uartTxDec((uint32_t)fuellstand);
			uartTxStr(" mAh      ");
			uartTx(0x0D); // wagenrücklauf ohne neue Zeile!!!
			
			if (ulokal > modus_lader_ladeschlussspannung) {
				; // CV mode, noch warten bis I klein genug
			} else {
				setPowerOutput(tempspannung);
				delayms(10); // Erhöhung der Regelzeitkonstate
			}
			wdt_reset();
		}
	}
	// Akku voll oder Error Abbruch
	ntOn(0);
	delayms(100);
	if (state == LADEN_AKTIV) { // Ladungsabbruch durch Knopfdruck
		state = MODUS_LADER;
	}
}
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
int main(void) {
	DDRB  = 1<<PB0 | 1<<PB2 | 1<<PB3 | 1<<PB5;
	DDRC  = 1<<PC3 | 1<<PC5;
	DDRD  = 1<<PD1 | 1<<PD5 | 1<<PD6 | 1<<PD7;
	// Pullups
	PORTD = 1<<PD4;
	
	// Sicherer Start nach Boot des Geräts:
	ntOn(0);
	
	// Pinchange Interrupts für das Drehrad und den Knopf
	// Knopf hängt am PCINT20 (PD4)
	EICRA = 1<<ISC11 | 1<<ISC10 | 1<<ISC01 | 1<<ISC00;
	EIMSK = 1<<INT1 | 1<<INT0;
	PCICR = 1<<PCIE2; // PCINT16 bis 23 aktiv
	PCMSK2 = 1<<PCINT20; // Interrupt auf fallender UND steigender Flanke von PD4
	
	delayms(100); // wait for clock stabilize
	
	// init der Module
	i2c_init();
	uartInit();
	#ifdef FERNSTEUERUNG
	// UART Receive Complete Interrupt für Fernsteuerung
	UCSR0B |= 1<<RXCIE0;
	#endif
	adcInit();
	timerInit();
	spiInit();
	SS_DAC(1); // CS vom DAC ist idle high
	for(uint8_t i=0; i<3; i++) { // Display braucht noch mehrere Anläufe :D
		DOGM163_init();
		display_clear();
		display_return_home();
	}
	delayms(100);
	
	setPowerOutput(5000); // setze DAC, damit kein Überschwinger beim ersten Start passiert.
	
	uartTxPstrln(PSTR("Guten Tag!"));
// 	uartTxPstrln(PSTR("REICH TIME"));
	uartTxNewline();
	uartTxPstrln(PSTR("Hilfe: die Eingabe muss mittels Tastatur erfolgen, das Zeilenende \
ist ein 0x0D"));
	uartTxNewline();
	
	spi_write_string("   Guten Tag!     gebaut von    Toni und Philipp"); // Begrüßung
	LED(1);
	delayms(1000);
	
	sei(); // und es seien Interrupts (aktiv)!
	
	SPKR(1);
	delayms(100);
	SPKR(0);
	stateMachine();
	return 0;
}

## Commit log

2014-11-11 1st commit from VT7, lib für den DAC erstellt und readme weitergeschrieben.
2014-11-11 datenblätter für DAC und spannungswandler
2014-11-12 Update README.md
    Umbau auf 60V
2014-11-13 app note von TI hinzugefügt
    [server_lader.sch]
2014-11-13 work Datenblatt hinzugefügt
    [server_lader.sch]
2014-11-15 layout fertig
    [server_lader.kicad_pcb, server_lader.sch]
2014-11-15 ps files added
    [server_lader.kicad_pcb, server_lader.sch]
2014-11-15 submodule für die lib des LCDs erstellt.
2014-11-15 pr0gramm geht los. Gleitmittelwerte für alle ADC-Messungen um Ungenauigkeiten zu vermindern.
2014-11-16 DOGlib und ein paar Änderungen am lader.c
2014-11-16 vermessung der Regelspannung im Verhältnis zur Ausgangsspannung
2014-11-16 pr0gramm geht weiter. Viele Interrupts bestimmen den Programmablauf!
2014-11-16 Berechnung für die DAC-Stellwerte in Abhängigkeit von der gewünschten Ausgangsspannung
2014-11-16 fehler entfernt
    [Regelspannung_zu_Ausgangsspannung.ods]
2014-11-16 kleine Änderungen
    [server_lader.kicad_pcb, server_lader.sch]
2014-11-16 ein paar Bilderlein zum MOD der OVLO.
2014-11-17 footprint of fuseholder changed
    [server_lader.kicad_pcb]
2014-11-17 ADC änderungen
2014-11-18 anfang der menüstruktur und der Regelung
2014-11-23 für Fertigung vorbereitet
    [server_lader.kicad_pcb]
2014-11-28 neue Dateien - Version so gefertigt.
    [server_lader.sch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]
2014-11-28 programm tut noch nicht vollständig, Timer und ADC laufen.
2014-11-29 flowchart.c hinzugefügt
2014-11-29 compiles without errors but still a lot of work to do
    [lader.c]
2014-11-30 bugfixes und Vormerkungen für nächsten Version
    [server_lader.sch]
2014-12-01 neue Bilder und Regelung für den Netzteilmodus
2014-12-01 Datenblätter und Schaltplananpassungen wegen neuem OPV im Ausgangszweig
    [server_lader.kicad_pcb, server_lader.sch]
2014-12-02 Fehlercodes und deren Verarbeitung dazu, Modus Netzteil
2014-12-02 Laderegelung sollte fertig sein, Netzteil auch. UART spuckt schon ein paar Daten aus, Energiemessung noch NICHT fertig.
2014-12-03 bugfixes Stromanzeige ist fehlerhaft
    [lader.c]
2014-12-03 fertig zum testen TODO: beim lesen der variablen strom interrupts sperren
2014-12-05 interruptsicherheit in netzteil und lader erhöht
2014-12-06 lader geht jetzt *wirklich*, Netzteil sowieso.
2014-12-30 Bilder von einem Aufbau des Laders mit industriell gefertigter Platine, allerdings noch ohne Display
2015-01-01 Datenblatt vom i2c Protokoll dazugefügt und fernsteuerung für lader so weit fertig, dass es getestet werden kann (WiP)
2015-02-03 fernsteuerung jetzt auch für den Lademodus - allerdings noch etwas buggy
    [lader.c]
2015-02-18 fersteuerung weiter - aufhängung noch nicht behoben!
    [lader.c]
2015-03-06 Fernsteuercode neu geschrieben und stark vereinfacht. Aufhänger nicht mehr reproduzierbar.
2015-03-07 watchdog integriert und Fernsteuerung weiter
2015-03-09 Regelung im Netzteilmodus konnte springen - behoben
    [lader.c]
2015-03-09 Netzteil: Überspannungsschwellwert auf 1,5V gestellt und RampUp-Behandlung mit einem eigenen Errorstate verbaut. bei Reglerwert > 3V gibt es einen Fehler.
    [lader.c]
2015-11-15 logo hinzugefügt
    [server_lader.kicad_pcb]
2015-12-29 Anzeigefehler bei der Stromeinstellung behoben
    [lader.c]
2016-06-26 Layout verbessert und weitere Hinweise zum Modding geschrieben
2016-06-26 rescue_lib für schaltplan angelegt
    [server_lader.sch]

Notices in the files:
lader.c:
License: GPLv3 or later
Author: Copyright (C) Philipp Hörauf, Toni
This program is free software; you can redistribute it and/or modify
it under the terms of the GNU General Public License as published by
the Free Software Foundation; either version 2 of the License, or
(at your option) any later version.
